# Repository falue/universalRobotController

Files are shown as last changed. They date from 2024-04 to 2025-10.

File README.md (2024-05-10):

# Universal Robot Control (RX/TX)

## Introduction

This repository includes transmitter (TX) and receiver (RX) arduino files for a remote controlled robot of any form.

The transmitter is a custom build to have full control over input mixing, skewing and do all sorts of dependencies.
It depends on a custom PCB, or like a thousand wires.
The receiver end can be a robot or whatever.

This relies on OrangeRx products by hobbyking for Tx/Rx and uses the (legacy) DSM2/DSMX† protocols for a reliable, digital communication.
with a "range of up to 3km (line of sight)".
I'm sure though this works with any RC transmitter that uses iBUs / ppm.

> Based on James Brutons RemoteDSM:
> 
> [https://github.com/XRobots/RemoteDSM ↗](https://github.com/XRobots/RemoteDSM)
> 
> [https://youtu.be/5BfRg9CUMYI ↗](https://youtu.be/5BfRg9CUMYI)

† "*The DSM in DSMX stands for Digital Spectrum Modulation and is what creates pure digital control providing an impenetrable radio link immune to all types of interference.*" ([Soruce ↗](https://www.spektrumrc.com/spm-bs-dsmx.html#:~:text=The%20DSM%20in%20DSMX%20stands,to%20all%20types%20of%20interference.))

# Transmission speed
Depending if you need 10 or 20 channels you can choose to use a second transmitter.
The second transmitter leads to more fluctation and/or longer duration of the main `loop()` though. If you need snappy response times, reconsider using a second transmitter.

|Num of Transmitters|Range (ms)|Average (ms)|Median (ms)|
|--|--|--|--|
|1|30-69|31|32|
|2|28-70|45|33|

# Hardware
## TX
- [Arduino Mega ↗](https://store.arduino.cc/products/arduino-mega-2560-rev3)
- One thousand switches and buttons
- One thousand linear potentiometers
- Two three-axis joysticks (ali express article [1↗](https://de.aliexpress.com/item/4001270851701.html) or [2↗](https://de.aliexpress.com/item/1005002965907648.html)) with a pushbutton
- A custom PCB (files here: [gerber.zip](kicad/universalRobotTx/gerber/gerber.zip) | [kicad](kicad/universalRobotTx))
- A laser cut case (files here: [ai](cad/universal_robot_laser.ai) | [dxf](cad/universal_robot_laser.dxf) | [svg](cad/universal_robot_laser.svg))
- One (or two) [OrangeRX DSMX DSM2 transmitter ↗](https://hobbyking.com/en_us/orangerx-dsmx-dsm2-compatible-2-4ghz-transmitter-module-v1-2.html)
- *..extensive list has to follow*

## RX
- [Arduino Leonardo (or UNO) ↗](https://store.arduino.cc/products/arduino-leonardo-with-headers)
- [Arduino Motor Shield Rev3 ↗](https://store.arduino.cc/products/arduino-motor-shield-rev3)
- One  (or two) [OrangeRx RR12RDTS Receiver ↗](https://hobbyking.com/en_us/orangerx-rr12rdts-receiver-with-s-link-dsm2-dsmx-compatible.html)
- [OrangeRx Program box ↗](https://hobbyking.com/en_us/orangerx-program-box-for-r620x-r1220x-v3-rr12rdts-receivers.html)
- *..extensive list has to follow*

---

# OrangeRx setup

## OrangeRx Receiver re-programming
As the Windows software "[rx_secure_configurator ↗](https://cdn-global-hk.hobbyking.com/media/file/r/x/rx_secure_configurator.zip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)" for the [receiver ↗](https://hobbyking.com/en_us/orangerx-rr12rdts-receiver-with-s-link-dsm2-dsmx-compatible.html) to set some settings on the receiver is **very** buggy, buy the [OrangeRx Program box ↗](https://hobbyking.com/en_us/orangerx-program-box-for-r620x-r1220x-v3-rr12rdts-receivers.html).
1. Connect the jumper to power the receiver from the program box to pin 1 and 2.
2. Set the "out type" from default "*SBus*" to "*iBUS*"
3. Set the *FailSafe" to send "1500" on all channels when losing connection; to be able to detect signal loss on the receiver

## OrangeRx Binding Process
1. Power off remote.
2. Power on robot receiver. Its LED flashes fast yellow to indicate that there is no connection.
2. Press "Bind" button on transmitter.
3. Power on remote (!); keep "Bind" button pressed.
4. remote beeps three times; robot receiver stops flashing and has now a continous light. congrats.
5. From here on out, connection is established.

> 📝 NOTE: Red LED on remote (on the transmitter) does not turn on if no signal is sent to the PPM pin.
> 
> 📝 NOTE: Always power on robot receiver first, then remote.
> 
> 📝 NOTE: If turned off remote while robot receiver is on, restart robot receiver as well to reset connection.
> Turning off robot receiver while remote is still on, restarting robot receiver again auto connects again.

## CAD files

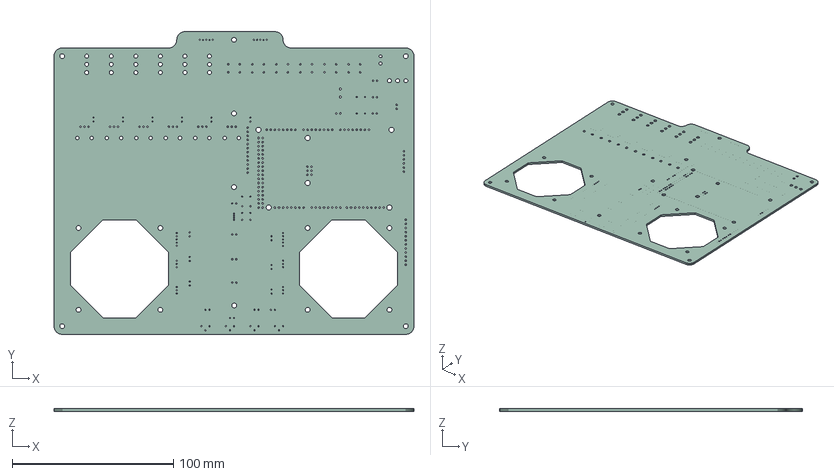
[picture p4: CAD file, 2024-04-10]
kicad/universalRobotTx/universalRobotTx.step
223.5 x 188.0 x 1.60 mm

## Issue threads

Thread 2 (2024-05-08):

Use math functions for changing user input

falue, 2024-05-08:
Use math functions of curves of potis (aka make an exponential potentiometer out of a linear one, or make something irregular)

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

falue, 2024-05-08:
maybe add mini screen for this ?

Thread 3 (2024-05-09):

Servos still jitter

falue, 2024-05-09:
either data from transmitter is sent jittering or the transmission is

solution:
A) solder capacitor into transmitter as planned (might do nothing)
B) additional fast smoothing of the smoothed servo values

did not work
- playing around with capacitor on servo power line

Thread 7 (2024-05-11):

Smoothing of servo PWM - take different loop() speeds into account

falue, 2024-05-11:
TX sends:
`95,100,105,110`
-> one integer per 30ms/loop(), but the RX receives each 2ms/loop():
`95,95,95,95,100,100,100,100,100,100,105,105,105,105,105,110,110,110,110`
-> this will be interpolated as
`98,98,98,100,100,100,100,100,103,105,105,105,105,108,108,108`
(small steep curves, stair like result) instead of a big curve:
`97,98,99,101,102,103,104,105,106,107,108,109110`

Solution:
loop of TX takes around 30ms, loop of RX only around 2ms.
either:
- add ~28ms delay in TX loop (poor choice)
or
- only interpolate values every 15 loops() fo the RX
or
- only interpolate values when the oldValue != currentValue
or
- use time-insensitive smoothing function

falue, 2024-05-11:
or:
```
if(millis() % 30 <= 5) {
  currentSmoothedX = exponentialMovingAverage(X, smoothedValueX, smoothingX);
}
```

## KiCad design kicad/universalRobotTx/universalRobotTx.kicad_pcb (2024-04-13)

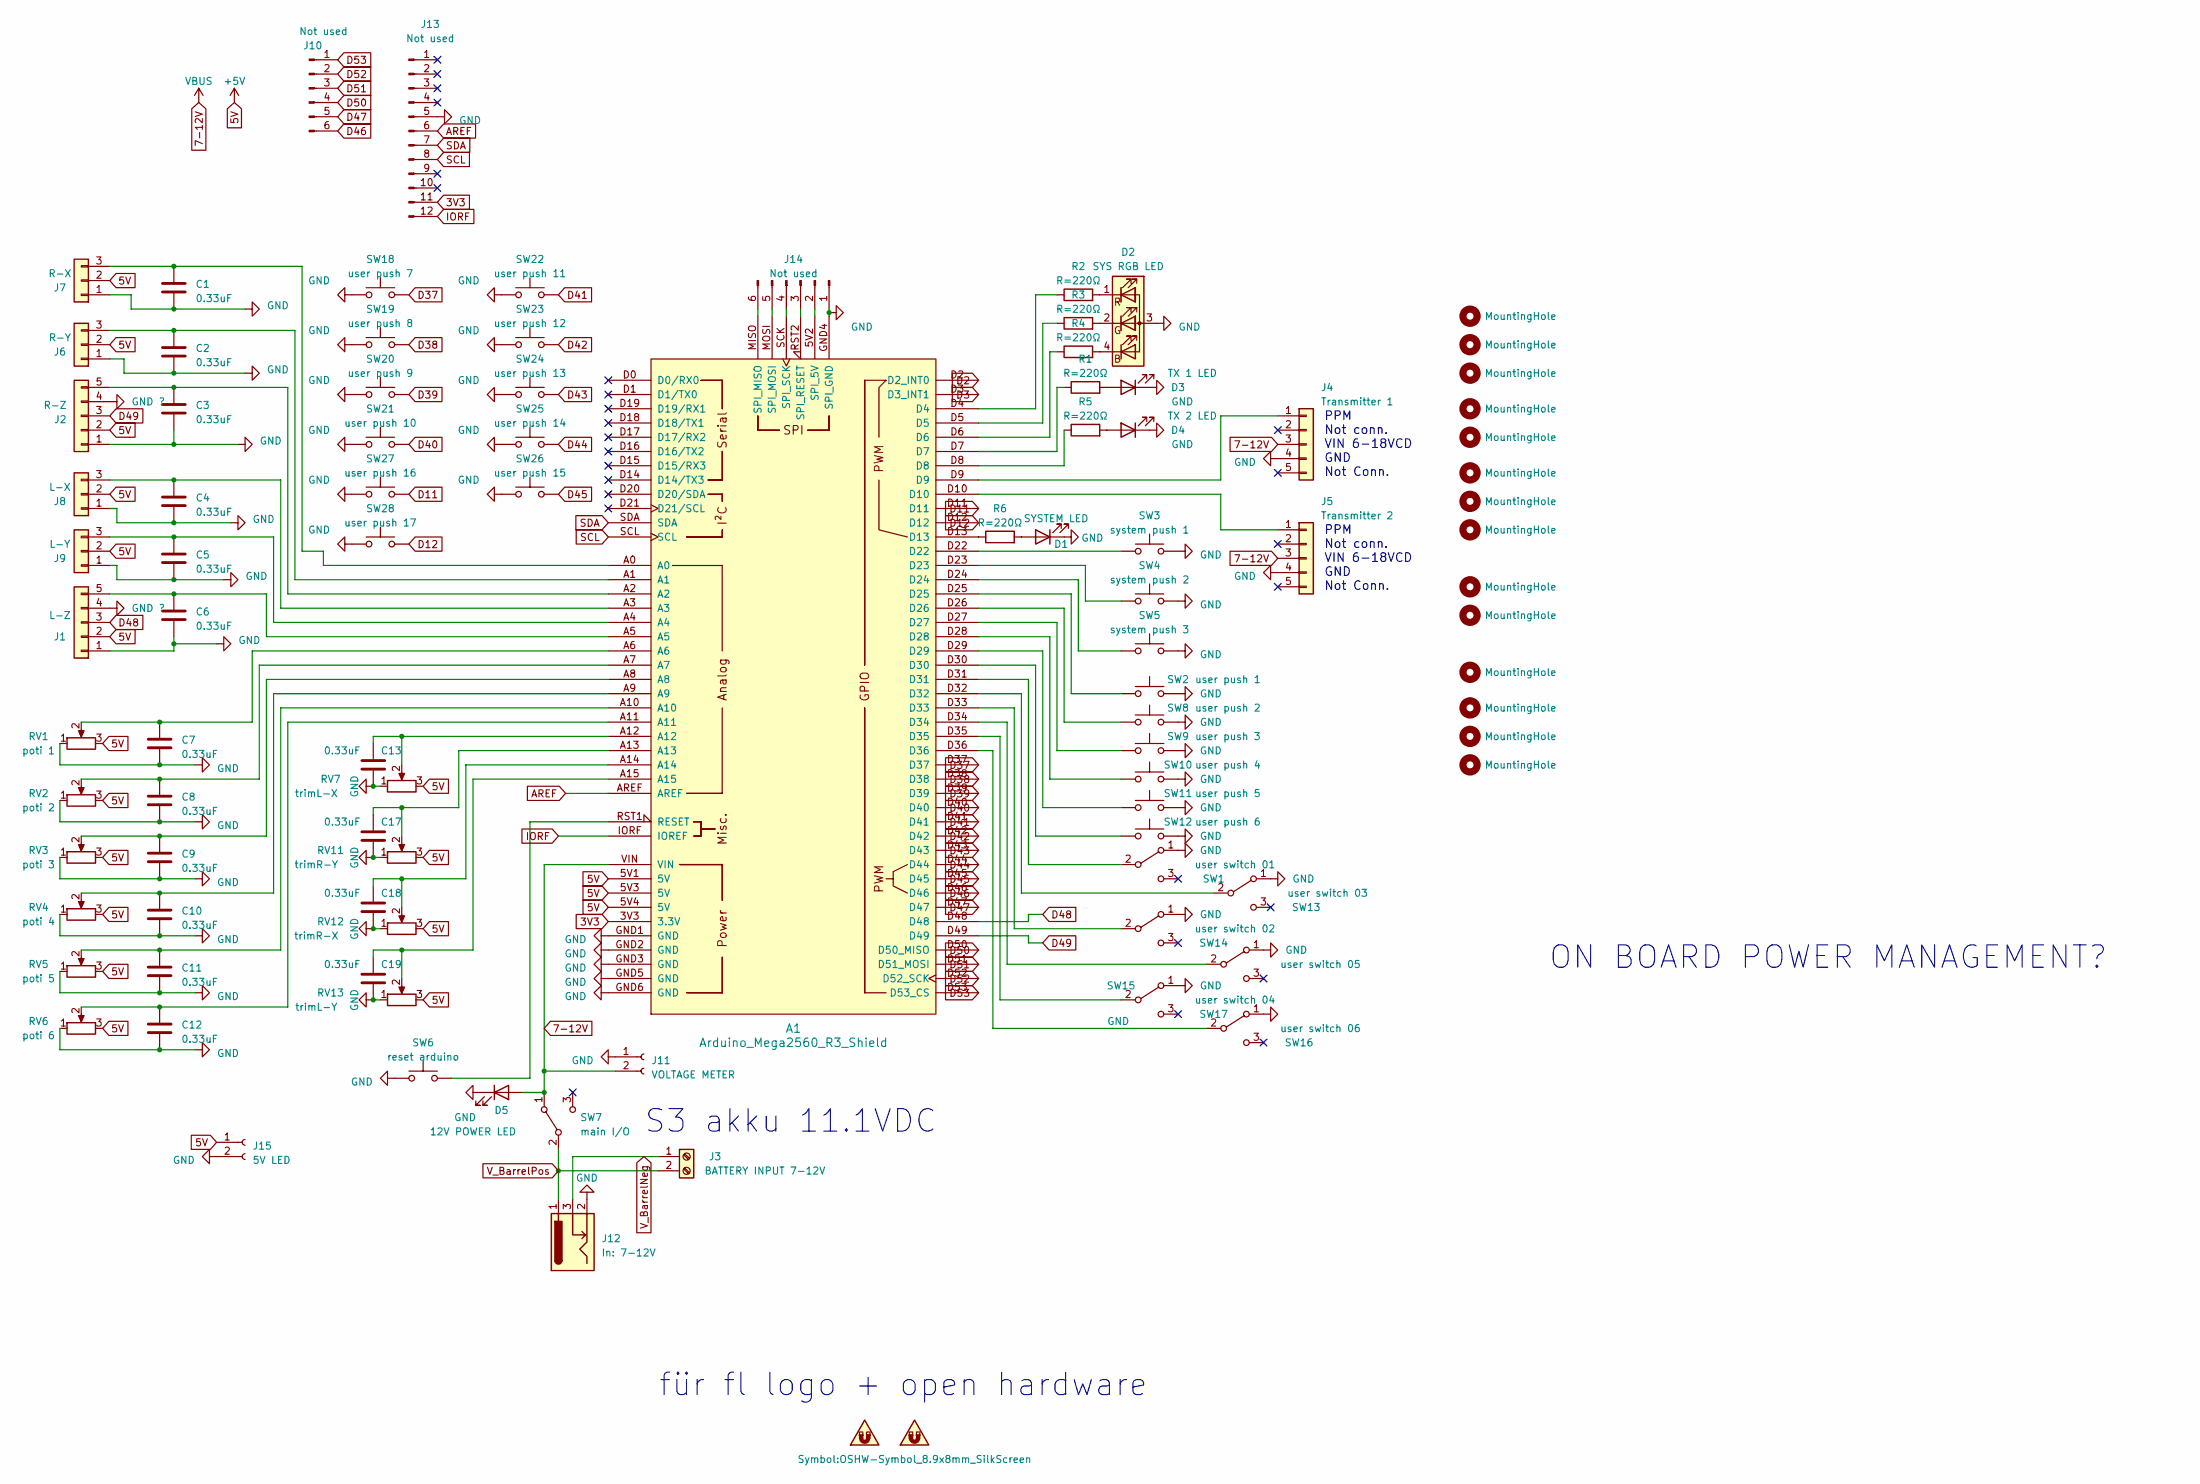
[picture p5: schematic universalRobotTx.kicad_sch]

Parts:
A1: Arduino_Mega2560_R3_Shield
C1, C2, C3, C4, C5, C6, C7, C8, C9, C10, C11, C12, C13, C17, C18, C19: 0.33uF; C_Disc_D7.0mm_W2.5mm_P5.00mm
D1: SYSTEM LED; LED_D3.0mm
D2: SYS RGB LED; LED_D5.0mm-4_RGB_Wide_Pins
D3: TX 1 LED; LED_D3.0mm
D4: TX 2 LED; LED_D3.0mm
D5: 12V POWER LED; LED_D3.0mm
H7: MountingHole; MountingHole_3mm
J1: L-Z; JST_PH_B5B-PH-K_1x05_P2.00mm_Vertical
J2: R-Z; JST_PH_B5B-PH-K_1x05_P2.00mm_Vertical
J3: BATTERY INPUT 7-12V; TerminalBlock_Phoenix_MKDS-1,5-2-5.08_1x02_P5.08mm_Horizont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
J4: Transmitter 1; JST_PH_B5B-PH-K_1x05_P2.00mm_Vertical
J5: Transmitter 2; JST_PH_B5B-PH-K_1x05_P2.00mm_Vertical
J6: R-Y; JST_PH_B3B-PH-K_1x03_P2.00mm_Vertical
J7: R-X; JST_PH_B3B-PH-K_1x03_P2.00mm_Vertical
J8: L-X; JST_PH_B3B-PH-K_1x03_P2.00mm_Vertical
J9: L-Y; JST_PH_B3B-PH-K_1x03_P2.00mm_Vertical
J10, J14: Not used; PinHeader_1x06_P2.54mm_Vertical
J11: VOLTAGE METER; JST_EH_B2B-EH-A_1x02_P2.50mm_Vertical
J12: In: 7-12V; BarrelJack_Kycon_KLDX-0202-xC_Horizontal
J13: Not used; PinHeader_1x12_P2.54mm_Vertical
J15: 5V LED; JST_EH_B2B-EH-A_1x02_P2.50mm_Vertical
R1, R2, R3, R4, R5, R6: R=220Ω; R_Axial_DIN0309_L9.0mm_D3.2mm_P5.08mm_Vertical
RV1: poti 1; Potentiometer_Bourns_PTV09A-1_Single_Vertical
RV2: poti 2; Potentiometer_Bourns_PTV09A-1_Single_Vertical
RV3: poti 3; Potentiometer_Bourns_PTV09A-1_Single_Vertical
RV4: poti 4; Potentiometer_Bourns_PTV09A-1_Single_Vertical
RV5: poti 5; Potentiometer_Bourns_PTV09A-1_Single_Vertical
RV6: poti 6; Potentiometer_Bourns_PTV09A-1_Single_Vertical
RV7: trimL-X; Potentiometer_Bourns_3386X_Horizontal
RV11: trimR-Y; Potentiometer_Bourns_3386X_Horizontal
RV12: trimR-X; Potentiometer_Bourns_3386X_Horizontal
RV13: trimL-Y; Potentiometer_Bourns_3386X_Horizontal
SW1: user switch 01; Toggle_switch_3P_5.08
SW2: user push 1; SW_TH_Tactile_FL_thingy
SW3: system push 1; Drucktaster_FL_Mentor_1852.6231
SW4: system push 2; Drucktaster_FL_Mentor_1852.6231
SW5: system push 3; Drucktaster_FL_Mentor_1852.6231
SW6: reset arduino; Drucktaster_FL_Mentor_1852.6231
SW7: main I/O; Toggle_switch_3P_5.08
SW8: user push 2; SW_TH_Tactile_FL_thingy
SW9: user push 3; SW_TH_Tactile_FL_thingy
SW10: user push 4; SW_TH_Tactile_FL_thingy
SW11: user push 5; SW_TH_Tactile_FL_thingy
SW12: user push 6; SW_TH_Tactile_FL_thingy
SW13: user switch 03; Toggle_switch_3P_5.08
SW14: user switch 02; Toggle_switch_3P_5.08
SW15: user switch 05; Toggle_switch_3P_5.08
SW16: user switch 06; Toggle_switch_3P_5.08
SW17: user switch 04; Toggle_switch_3P_5.08
SW18: user push 7; SW_Push_1P2T_Horizontal_FL_RND_210-00255
SW19: user push 8; SW_Push_1P2T_Horizontal_FL_RND_210-00255
SW20: user push 9; SW_Push_1P2T_Horizontal_FL_RND_210-00255
SW21: user push 10; SW_Push_1P2T_Horizontal_FL_RND_210-00255
SW22: user push 11; SW_Push_1P2T_Horizontal_FL_RND_210-00255
SW23: user push 12; SW_Push_1P2T_Horizontal_FL_RND_210-00255
SW24: user push 13; SW_Push_1P2T_Horizontal_FL_RND_210-00255
SW25: user push 14; SW_Push_1P2T_Horizontal_FL_RND_210-00255
SW26: user push 15; SW_Push_1P2T_Horizontal_FL_RND_210-00255
SW27: user push 16; SW_Push_1P2T_Horizontal_FL_RND_210-00255
SW28: user push 17; SW_Push_1P2T_Horizontal_FL_RND_210-00255

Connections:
3V3: A1.3V3 (3.3V), J13.11
5V: A1.5V1 (5V), A1.5V3 (5V), A1.5V4 (5V), J1.2, J2.2, J6.2, J7.2, J8.2, J9.2, J15.1, RV1.3, RV2.3, RV3.3, RV4.3, RV5.3, RV6.3, RV7.3, RV11.3, RV12.3, RV13.3
7-12V: A1.VIN, D5.2 (A), J4.3, J5.3, J11.2, SW7.1 (A)
AREF: A1.AREF, J13.6
D2: A1.D2 (D2_INT0)
D3: A1.D3 (D3_INT1)
D11: A1.D11, SW27.2
D12: A1.D12, SW28.2
D37: A1.D37, SW18.2
D38: A1.D38, SW19.2
D39: A1.D39, SW20.2
D40: A1.D40, SW21.2
D41: A1.D41, SW22.2
D42: A1.D42, SW23.2
D43: A1.D43, SW24.2
D44: A1.D44, SW25.2
D45: A1.D45, SW26.2
D46: A1.D46, J10.6
D47: A1.D47, J10.5
D48: A1.D48, J1.3
D49: A1.D49, J2.3
D50: A1.D50 (D50_MISO), J10.4
D51: A1.D51 (D51_MOSI), J10.3
D52: A1.D52 (D52_SCK), J10.2
D53: A1.D53 (D53_CS), J10.1
IORF: A1.IORF (IOREF), J13.12
unnamed: A1.A6, C7.1, RV1.2
unnamed: A1.A7, C8.1, RV2.2
unnamed: A1.A8, C9.1, RV3.2
unnamed: A1.A9, C10.1, RV4.2
unnamed: A1.A10, C11.1, RV5.2
unnamed: A1.A11, C12.1, RV6.2
unnamed: A1.A12, C13.1, RV7.2
unnamed: A1.A13, C17.1, RV11.2
unnamed: A1.A14, C18.1, RV12.2
unnamed: A1.A15, C19.1, RV13.2
unnamed: A1.D4, R2.1
unnamed: A1.D5, R3.1
unnamed: A1.D6, R4.1
unnamed: A1.D7, R1.1
unnamed: A1.D8, R5.1
unnamed: A1.D13, R6.1
unnamed: A1.D22, SW3.1
unnamed: A1.D23, SW4.1
unnamed: A1.D24, SW5.1
unnamed: A1.D25, SW2.1
unnamed: A1.D26, SW8.1
unnamed: A1.D27, SW9.1
unnamed: A1.D28, SW10.1
unnamed: A1.D29, SW11.1
unnamed: A1.D30, SW12.1
unnamed: A1.RST1 (RESET), SW6.2
unnamed: A1.5V2 (SPI_5V), J14.2
unnamed: A1.MISO (SPI_MISO), J14.6
unnamed: A1.MOSI (SPI_MOSI), J14.5
unnamed: A1.RST2 (SPI_RESET), J14.3
unnamed: A1.SCK (SPI_SCK), J14.4
unnamed: D1.2 (A), R6.2
unnamed: D2.4 (BK), R4.2
unnamed: D2.2 (GK), R3.2
unnamed: D2.1 (RK), R2.2
unnamed: D3.2 (A), R1.2
unnamed: D4.2 (A), R5.2
unnamed: A1.A5, C6.1, J1.5
unnamed: A1.A2, C3.1, J2.5
unnamed: A1.D9, J4.1
unnamed: A1.D10, J5.1
unnamed: A1.A1, C2.1, J6.3
unnamed: A1.A0, C1.1, J7.3
unnamed: A1.A3, C4.1, J8.3
unnamed: A1.A4, C5.1, J9.3
unnamed: A1.D31, SW1.2 (B)
unnamed: A1.D32, SW13.2 (B)
unnamed: A1.D33, SW14.2 (B)
unnamed: A1.D34, SW15.2 (B)
unnamed: A1.D36, SW16.2 (B)
unnamed: A1.D35, SW17.2 (B)
SCL: A1.SCL, J13.8
SDA: A1.SDA, J13.7
V_BarrelNeg: J3.1, J12.3
V_BarrelPos: J3.2, J12.1, SW7.2 (B)

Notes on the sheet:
PPM Not conn. VIN 6-18VCD GND Not Conn.
ON BOARD POWER MANAGEMENT?
S3 akku 11.1VDC
für fl logo + open hardware

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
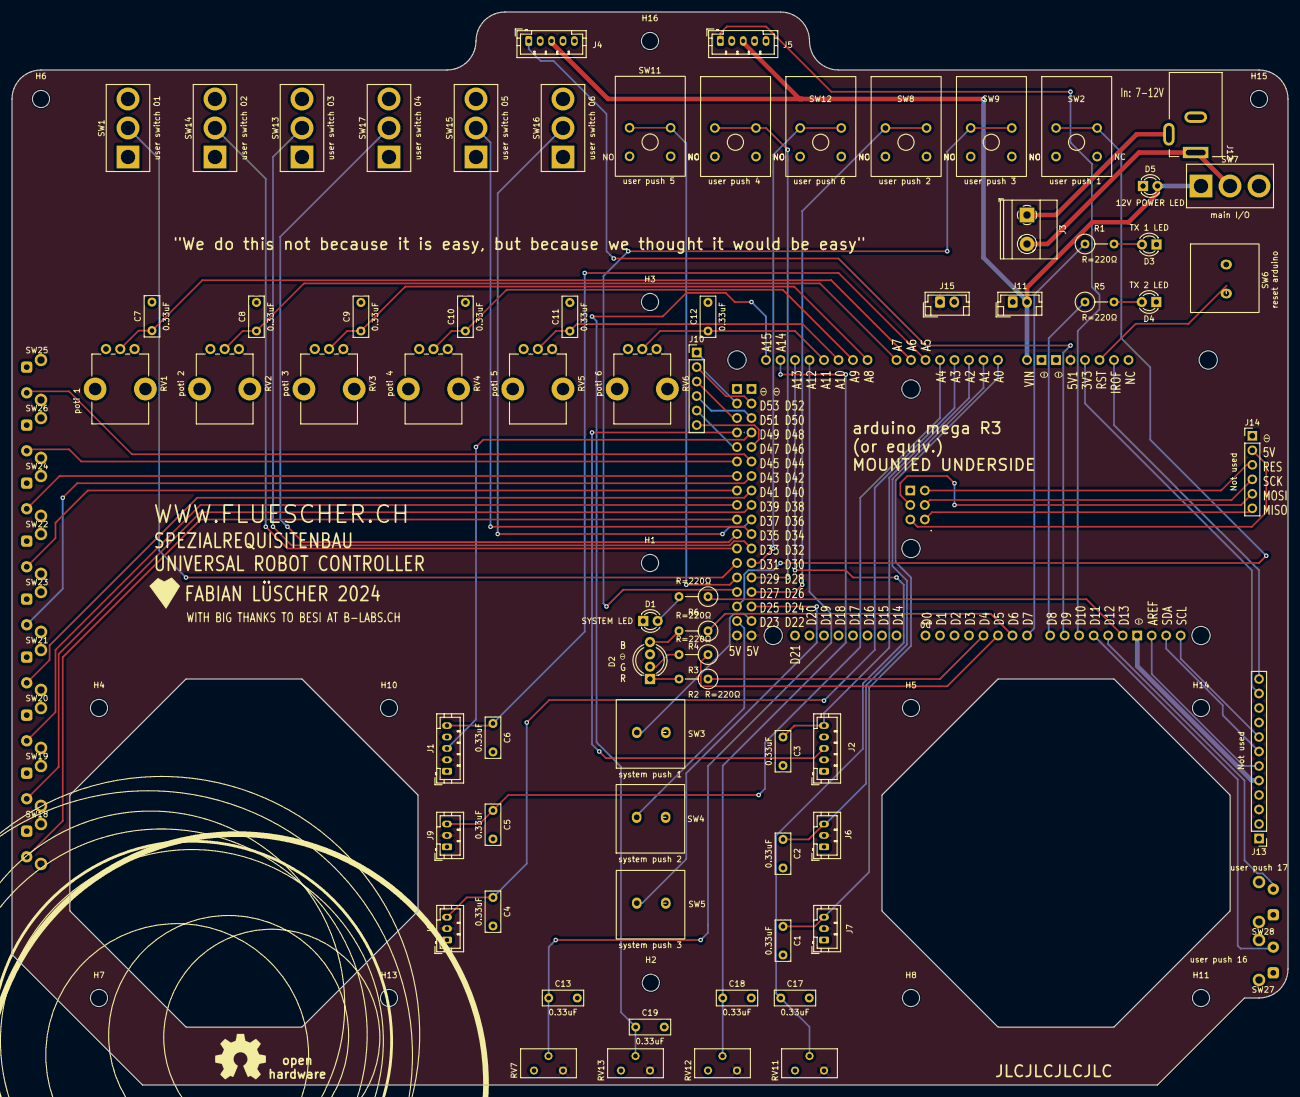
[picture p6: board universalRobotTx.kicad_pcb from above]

Board: 2 copper layers, 223.5 x 188.0 mm, 95 parts (0 on the bottom side), 80 nets.

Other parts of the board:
H1, H2, H3, H4, H5, H6, H8, H10, H11, H13, H14, H15, H16: MountingHole; MountingHole_3mm

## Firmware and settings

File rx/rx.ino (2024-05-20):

#include <IBusBM.h>  // https://github.com/bmellink/IBusBM
#include <Servo.h>

IBusBM IBus; // IBus object

Servo servoX;
Servo servoY;

// Options
bool enableDrive = false;          // Set by switch 2
bool enableHeadMovements = false;  // Set by switch 1
bool fakeRemoteInputs = false;     // If you do not have a RX connected, try this. Generates ramp-ups and -downs of joystiuck movement.
bool forceDisableMotors = false;    // Disable effective motor control, but keep calculations & serial prints

// Servos
int servoXPin = 2;
int servoYPin = 10;

// DC Motors
int directionPinA = 13;
int pwmPinA = 11;
int brakePinA =  8;

int directionPinB = 12;
int pwmPinB = 3;
int brakePinB =9;

// Remote channels
int joystickLX = 1500;
int joystickLY = 1500;
int joystickLZ = 1500;
int jostickRX = 1500;
int jostickRY = 1500;
int jostickRZ = 1500;
bool joyBtnL = false;
bool joyBtnR = false;
bool enableAcceleratedSmoothing = false;

// Unused btns
bool disableSteering = false;
bool userBtn1 = false;
bool userBtn2 = false;
// bool userBtn3 = false;  // not used
// bool userBtn4 = false;  // not used
// bool userBtn5 = false;  // not used
// bool userBtn6 = false;  // not used
int poti1 = 1500;
int poti2 = 1500;

bool decodedButtons0[4];
bool decodedButtons1[4];

// Smoothing servos
float smoothedValueX = float(jostickRX);
float smoothedValueY = float(jostickRY);
float smoothedValueZ = float(jostickRZ);

float currentSmoothedX = smoothedValueX;
float currentSmoothedY = smoothedValueY;

// Limit the max speed of the robot
// 0-254 *or* 0-100. This is up for dabate. The latter is mentioned in the docs of the
// motor shield r3 but a weird thing, usually things like that are 0-254.
int maxSpeed = 100;  // Changed by poti1
int minSpeed = 33;   // Below this, the motors do not turn bc. of friction and not being spherical cows in space
float headMovementSmoothing = 0.01;

// fakeRemoteInputs
int directionX = 1, directionY = 1, directionZ = 1;
int phase = 0;
int step = 2;
const int startValue = 1000;
const int endValue = 2000;

void setup() {
  delay(1666);

  Serial.begin(115200);
  
  // Establish IBus connection to receiver
  //   Change to Serial1 = D0 (or Serial2 or 3 for on ard mega or so) port when required
  //   The servo library conflicts with the interrupts used by the IBus library -
  //   Therefore, use second argument "IBUSBM_NOTIMER" to call the IBus.loop() function manually in the main loop
  IBus.begin(Serial1, IBUSBM_NOTIMER);

  // Attach head servos
  servoX.attach(servoXPin);
  servoY.attach(servoYPin);

  // Define motor pins
  pinMode(directionPinA, OUTPUT);
  pinMode(pwmPinA, OUTPUT);
  pinMode(brakePinA, OUTPUT);

  pinMode(directionPinB, OUTPUT);
  pinMode(pwmPinB, OUTPUT);
  pinMode(brakePinB, OUTPUT);
}

void loop() {
  if(!fakeRemoteInputs) {
    readChannels();
  } else {
    fakeJoystickValues();
  }

  detectLossOfSignal();

  debugPrints();

  drive(joystickLX, joystickLY, joystickLZ);

  if(enableDrive) {
    if(joyBtnL) {
      quickturn("joyBtnL", -180);
    }
    if(joyBtnR) {
      quickturn("joyBtnR", 180);
    }
    if(userBtn1) {
      quickturn("userBtn1", -5);
    }
    if(userBtn2) {
      quickturn("userBtn2", 5);
    }
  }
  

  if(enableHeadMovements) {
    if(!servoX.attached()) {
      servoX.attach(servoXPin);
      servoY.attach(servoYPin);
    }
    headMovement(jostickRX, jostickRY, jostickRZ);
  } else if(servoX.attached()) {
    servoX.detach();
    servoY.detach();
  }

  Serial.println("");
  // delay(5);  // Do not delay because IBus.loop() must be called as fast as possible
}


void fakeJoystickValues() {
    if(phase == 0 || phase == 3 || phase >= 4) {
      // Update Y
      if (joystickLY >= endValue || joystickLY <= startValue) {
          directionY *= -1;  // Reverse the direction
      }
      joystickLY += directionY * step;
      
      if(joystickLY <= startValue) {
        joystickLY = 1500;
        directionY = 1;
        phase++;
        delay(2000);
      }
    }

    if(phase == 1 || phase == 3 || phase >= 4) {
      // Update X
      if (joystickLX >= endValue || joystickLX <= startValue) {
          directionX *= -1;  // Reverse the direction
      }
      joystickLX += directionX * step;

      if(joystickLX <= startValue) {
        joystickLX = 1500;
        directionX = 1;
        phase++;
        delay(2000);
      }
    }

    if(phase == 2 || phase >= 4) {
      // Update Z
      if (joystickLZ >= endValue || joystickLZ <= startValue) {
          directionZ *= -1;  // Reverse the direction
      }
      joystickLZ += directionZ * step;
      
      if(joystickLZ <= startValue) {
        joystickLZ = 1500;
        directionZ = 1;
        phase++;
        delay(2000);
      }
    }

    String dirArrow = "";

    if(joystickLY > 1500) dirArrow += "▲";
    if(joystickLY < 1500) dirArrow += "▼";

    if(joystickLX > 1500) dirArrow += "►";
    if(joystickLX < 1500) dirArrow += "◄";

    if(joystickLZ > 1500) dirArrow += "⤵";
    if(joystickLZ < 1500) dirArrow += "⤴";

    // Output the current values and mixes to the Serial Monitor
    Serial.print("LX: "); Serial.print(joystickLX);
    Serial.print("\tLY: "); Serial.print(joystickLY);
    Serial.print("\tLZ: "); Serial.print(joystickLZ);
    Serial.print("\tsteering: ");
    Serial.print(dirArrow);
}

void readChannels() {
  // Call internal loop function to update the communication to the receiver.
  //   Needed if IBus.begin(); is called with second parameter "IBUSBM_NOTIMER"
  IBus.loop();
  int correction = -19;  // Somehow all the values are shifted 11-26 points (weighted median ~19)

  /*
  Sent by TX1:
    ch0: joystickLX
    ch1: joystickLY
    ch2: joystickLZ
    ch3: joystickRX
    ch4: joystickRY
    ch5: joystickRZ
    ch6: encodedButtons0 = {0: toggleSwitch1 1: toggleSwitch2 2: toggleSwitch3 3: toggleSwitch4}
    ch7: encodedButtons1 = {0: joyBtnL       1: joyBtnR       2: userBtn1      3: userBtn2}
    ch8: poti1
    ch9: poti2
  
  Sent by TX2 (if enabled):
    ch10: poti3
    ch11: poti4
    ch12: poti5
    ch13: poti6
    ch14: encodedButtons2 = {0: toggleSwitch5 1: toggleSwitch6 2: userBtn3  3: userBtn4}
    ch15: encodedButtons3 = {0: userBtn5      1: userBtn6      2: userBtn7  3: userBtn8}
    ch16: encodedButtons4 = {0: userBtn9      1: userBtn10     2: userBtn11 3: userBtn12}
    ch17: encodedButtons5 = {0: userBtn13     1: userBtn14     2: userBtn15 3: userBtn18}
    ch18: encodedButtons6 = {0: userBtn19     1: sysBtn1       2: sysBtn2   3: sysBtn3}
    ch19: 1500 (NC - not connected)
  */

  // Get the latest IBus data from cached data
  //   IMPORTANT: Somehow, some (?) channels are reordered by the TX or (!) RX
  joystickLY = IBus.readChannel(0) + correction;
  joystickLZ = IBus.readChannel(1) + correction;
  joystickLX = IBus.readChannel(2) + correction;
  jostickRX = IBus.readChannel(3) + correction;
  jostickRY = IBus.readChannel(4) + correction;
  jostickRZ = IBus.readChannel(5) + correction;
  
  // Add bool array to function because memory leaks
  decodeButtons(IBus.readChannel(6) + correction, decodedButtons0);
  decodeButtons(IBus.readChannel(7) + correction, decodedButtons1);

  enableDrive = decodedButtons0[0];
  enableHeadMovements = decodedButtons0[1];
  enableAcceleratedSmoothing = decodedButtons0[2];
  disableSteering = decodedButtons0[3];

  joyBtnL = decodedButtons1[0];
  joyBtnR = decodedButtons1[1];
  userBtn1 = decodedButtons1[2];
  userBtn2 = decodedButtons1[3];

  poti1 = IBus.readChannel(8) + correction;
  maxSpeed = map(poti1, 1000,2000, minSpeed,254);

  poti2 = IBus.readChannel(9) + correction;
  headMovementSmoothing = map(poti2, 1000,2000, 1,5000) / 100000.0;  // 0.01 is good, but can be less or up to 1
}

void debugPrints() {
  Serial.print("\tLX: ");
  Serial.print(joystickLX);
  Serial.print("\tLY: ");
  Serial.print(joystickLY);
  Serial.print("\tLZ: ");
  Serial.print(joystickLZ);
  Serial.print("\tRX: ");
  Serial.print(jostickRX);
  Serial.print("\tRY: ");
  Serial.print(jostickRY);
  Serial.print("\tRZ: ");
  Serial.print(jostickRZ);
  Serial.print("\tJBtnL: ");
  Serial.print(joyBtnL);
  Serial.print("\tJBtnR: ");
  Serial.print(joyBtnR);
  Serial.print("\tenDrive: ");
  Serial.print(enableDrive);
  Serial.print("\tenHead: ");
  Serial.print(enableHeadMovements);
  Serial.print("\tswitch3: ");
  Serial.print(enableAcceleratedSmoothing);
  Serial.print("\tswitch4: ");
  Serial.print(disableSteering);
  Serial.print("\tBtn1: ");
  Serial.print(userBtn1);
  Serial.print("\tBtn2: ");
  Serial.print(userBtn2);
  Serial.print("\tpot1: ");
  Serial.print(poti1);
  Serial.print("\tpot2: ");
  Serial.print(poti2);

  Serial.print("\tmaxSpeed: ");
  Serial.print(maxSpeed);
  Serial.print("\theadSmooth: ");
  Serial.print(headMovementSmoothing);
}

int calculateMotorSpeed(int Y, int X, int Z, char motorSide) {
  // TODO: Z is ignored now
  float mixer = 1.0;
  float minMixer = 0.5;
  // if full forward/backward and left, use 0.5
  // if full left, use 1.0
  mixer = 2.0 - map((abs(Y)+abs(X))*100, 0,maxSpeed*100, minMixer*100,100) / 100.0;
  mixer = clamp(mixer, 0.1, 1.0);
  
  int leftMotor = Y + int(X*mixer);
  int rightMotor = Y - int(X*mixer);
  
  leftMotor = clamp(leftMotor, -maxSpeed, maxSpeed);
  rightMotor = clamp(rightMotor, -maxSpeed, maxSpeed);
  
  if (motorSide == 'L') {
    Serial.print("\tmixer: ");
    Serial.print(mixer);
    return leftMotor;
  } else {
    return rightMotor;
  }
}

void drive(int X, int Y, int Z) {
  /* Terack movement */
  int deathZone = 30;  // 35, 50 works too
  // If walues chang only very little, nothing is being controlled, i.e. robot should be idling
  bool idle = isInDeathZone(X, 1500, deathZone) && isInDeathZone(Y, 1500, deathZone) && isInDeathZone(Z-165, 1500, deathZone);  // Z-165 because cheap joystick & cannot be trimmed

  // Values between 1000 and 2000
  X = clampMap(X, 1000,2000, -maxSpeed,maxSpeed);
  Y = clampMap(Y, 1000,2000, -maxSpeed,maxSpeed);
  Z = clampMap(Z, 1000,2000, maxSpeed,-maxSpeed);  // invert Z axis for some reason

  if(disableSteering) {
    X = 0;
  }

  // TODO: use Z for something
  /*if(abs(Z-1500) > abs(X-1500)) {
    X = Z < 1500 ? min(X, Z) : max(X, Z);
  }*/

  if(idle || !enableDrive) {
    // Remote is not touched - engange breaks and do nothing
    digitalWrite(brakePinA, HIGH);
    digitalWrite(brakePinB, HIGH);
    analogWrite(pwmPinA, 0);
    analogWrite(pwmPinB, 0);
  } else {
    // Release breaks
    digitalWrite(brakePinA, LOW);
    digitalWrite(brakePinB, LOW);

    // Mix X Y Z together
    // Get values between -maxSpeed and maxSpeed
    int motorL = calculateMotorSpeed(Y, X, Z, 'L');
    int motorR = calculateMotorSpeed(Y, X, Z, 'R');

    // Set direction
    digitalWrite(directionPinA, motorL < 0);  // LOW to reverse
    digitalWrite(directionPinB, motorR < 0);  // LOW to reverse

    Serial.print("\tmotorL: ");
    Serial.print(motorL);
    Serial.print("\tdir_motorL: ");
    Serial.print(motorL < 0 ? "back" : "forward");
    Serial.print("\tmotorR: ");
    Serial.print(motorR);
    Serial.print("\tdir_motorR: ");
    Serial.print(motorR < 0 ? "back" : "forward");

    // Power to the motors
    if(!forceDisableMotors) {
      analogWrite(pwmPinA, abs(motorL));  // abs makes out of -50 +50
      analogWrite(pwmPinB, abs(motorR));  // abs makes out of -50 +50
    }
  }

  Serial.print("\tmotorL: ");
  Serial.print(0);
  Serial.print("\tdir_motorL: ");
  Serial.print("idle");
  Serial.print("\tmotorR: ");
  Serial.print(0);
  Serial.print("\tdir_motorR: ");
  Serial.print("idle");
}


 bool debounce(String btnName) {
  bool btnState = true;
  while(btnState) {
    readChannels();
    if (btnName == "joyBtnL") {
      btnState = joyBtnL;
    } else if (btnName == "joyBtnR") {
      btnState = joyBtnR;
    } else if (btnName == "userBtn1") {
      btnState = userBtn1;
    } else if (btnName == "userBtn2") {
      btnState = userBtn2;
    } else {
      Serial.println("This btn has to be hard coded here to be debounced");
      btnState = false;
    }
    Serial.print(btnName);
    Serial.println(" - wait for btn release");
    delay(1);
  }
}

void quickturn(String btnName, int deg) {
  // On the press of a joystick or user button, make a quickturn left or right
  debounce(btnName);  // Waits for btn release

  // Release breaks
  digitalWrite(brakePinA, LOW);
  digitalWrite(brakePinB, LOW);
  digitalWrite(directionPinA, deg > 0 ? LOW : HIGH);   // LOW to reverse
  digitalWrite(directionPinB, deg < 0 ? LOW : HIGH);   // LOW to reverse
  analogWrite(pwmPinA, 100);
  analogWrite(pwmPinB, 100);
  int durationOfTurn = abs(deg)*2.6;
  Serial.println("Fast turn duration: ");
  Serial.print(durationOfTurn);
  delay(durationOfTurn); // Depends on ground and grip of tracks
}

bool isInDeathZone(int value, int idleValue, int deathZone) {
  bool isBelow = value < idleValue - deathZone;
  bool isAbove = value > idleValue + deathZone;
  return !(isBelow || isAbove);
}

// Function to calculate exponential moving average for a given sensor value
float exponentialMovingAverage(float newValue, float& smoothedValue, float smoothingFactor) {
  // smoothingFactor: 1=no smoothing; 0.0001 = much please yes smoothing but slow
  smoothedValue = (newValue * smoothingFactor) + (smoothedValue * (1 - smoothingFactor));
  return smoothedValue;
}

void headMovement(int X, int Y, int Z) {
  /* Servo Head movement */
  // Values between 1000 and 2000
  // No matter if the stick is leaning halfway in any direction, but its turned
  //   fully, always take the bigger (or smaller) value of Z
  if(abs(Z-1500) > abs(X-1500)) {
    X = Z < 1500 ? min(X, Z) : max(X, Z);
  }

  // Smooth out the signal
  float smoothingX = headMovementSmoothing;  // Depends on loop speed
  float smoothingY = smoothingX/2.0;  // Depends on loop speed

  // If X much greater than smoothedValueX, decrease smoothingX
  //   eg. if moving stick fast, increase responsiveness
  if(enableAcceleratedSmoothing) {
    if(abs(X - smoothedValueX) > 100) {
      smoothingX *= abs(X - smoothedValueX)/10;
    } else if(abs(Y - smoothedValueY) > 100) {
      smoothingY *= abs(Y - smoothedValueY)/10;
    }
    smoothingX = clamp(smoothingX, 0.0, .1);
    smoothingY = clamp(smoothingY, 0.0, .1);
  }

  currentSmoothedX = exponentialMovingAverage(X, smoothedValueX, smoothingX);
  currentSmoothedY = exponentialMovingAverage(Y, smoothedValueY, smoothingY);
  // float currentSmoothedZ = exponentialMovingAverage(Z, smoothedValueZ, 0.1);

  int servoValueX = map(currentSmoothedX, 1000, 2000, 1750, 2300);  // left, right
  servoX.writeMicroseconds(servoValueX);
  // Recenter head vertically
  int servoValueY = map(currentSmoothedY, 1000, 2000, 2050, 1675);  // up, down
  //servoValueY = clamp(servoValueY, 1675, 2050);  // recenter?
  servoY.writeMicroseconds(servoValueY);
}

int clamp(int value, int min, int max) {
   return value > max ? max : value < min ? min : value;
}

float clamp(float value, float min, float max) {
   return value > max ? max : value < min ? min : value;
}

int clampMap(int value, int valueFrom, int valueTo, int from, int to) {
  if(value < valueFrom) value = valueFrom;
  if(value > valueTo) value = valueTo;
  return map(value, valueFrom, valueTo, from, to);
}

void detectLossOfSignal() {
  // TODO: Does not work
  int failsaveValues = joystickLX + joystickLY + joystickLZ + jostickRX + jostickRY + jostickRZ + joyBtnL + joyBtnR + enableDrive + enableHeadMovements;
  int defaultValueSum = 8623;  //  technically: 6*1500 + 4*0, but IRL: 5*1500+1123 (first channel is 1123?!)
  if(failsaveValues == defaultValueSum) {  // Todo: Loss of signal detection somehow. Kind of the same as the idle state?!
    while(failsaveValues == defaultValueSum) {
      Serial.println("Loss of signal - wait for reconnection");
      readChannels();
      failsaveValues = joystickLX + joystickLY + joystickLZ + jostickRX + jostickRY + jostickRZ + joyBtnL + joyBtnR + enableDrive + enableHeadMovements;
      delay(25);
    }
  }
}

// Decode int from 1000 to 2000 and get array of 4 boolean values
bool* decodeButtons(int encodedValue, bool* buttonStates) {
    // Jitter of +/-32 can be handled
    // static bool buttonStates[4];  // Static to preserve state after the function returns

    // Define the exact encoded values for each combination of button states
    int encodedStates[16] = {
        1000, // 0000
        1066, // 0001
        1133, // 0010
        1200, // 0011
        1266, // 0100
        1333, // 0101
        1400, // 0110
        1466, // 0111
        1533, // 1000
        1600, // 1001
        1666, // 1010
        1733, // 1011
        1800, // 1100
        1866, // 1101
        1933, // 1110
        2000  // 1111
    };

    // Find the closest encoded state
    int closestIndex = 0;
    int smallestDifference = abs(encodedValue - encodedStates[0]);
    for (int i = 1; i < 16; i++) {
        int diff = abs(encodedValue - encodedStates[i]);
        if (diff < smallestDifference) {
            smallestDifference = diff;
            closestIndex = i;
        }
    }

    // Decode the closest index into button states
    buttonStates[0] = (closestIndex & 1) != 0;    // Least significant bit
    buttonStates[1] = (closestIndex & 2) != 0;    // Second bit
    buttonStates[2] = (closestIndex & 4) != 0;    // Third bit
    buttonStates[3] = (closestIndex & 8) != 0;    // Most significant bit

    return buttonStates;
}

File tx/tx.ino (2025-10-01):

/* 
  UNIVERSAL ROBOT CONTROLLER by FL
  with custom PCB
  based on james brutons remote controller
*/

// OPTIONS
bool trim = true;     // If true, poti 7,8,9,10 trim LX,LY,RX,RY. If false, those potis are not used.
int trimRange = 512;  // Plus minus half of that trims LX,LY,RX,RY
bool useSecondTransmitter = false;  // Send all btns and switches data over the second transmitter
String steeringLayout = "maxControl";
    // "conventional" => Use both joysticks with all three axis and their buttons, some switches, btns and potis (used for ProSenectute Robi), if useSecondTransmitter = true, use all buttons
    // "maxControl" => Use one joystick with one joyBtn, max use of buttons, switches and potis on one Transmitter module


// USER INPUT -------------------------------------
int toggleSwitch1Pin = 31;  // Switch on top, left
int toggleSwitch2Pin = 33;  // Switch on top
int toggleSwitch3Pin = 32;  // Switch on top
int toggleSwitch4Pin = 35;  // Switch on top
int toggleSwitch5Pin = 34;  // Switch on top
int toggleSwitch6Pin = 36;  // Switch on top, right

int userBtn1Pin = 29;  // push button on top, left
int userBtn2Pin = 28;  // push button on top
int userBtn3Pin = 30;  // push button on top
int userBtn4Pin = 26;  // push button on top
int userBtn5Pin = 27;  // push button on top
int userBtn6Pin = 25;  // push button on top, right

int userBtn7Pin = 44;   // push button on side left, top
int userBtn8Pin = 45;   // push button on side left
int userBtn9Pin = 43;   // push button on side left
int userBtn10Pin = 41;  // push button on side left
int userBtn11Pin = 42;  // push button on side left
int userBtn12Pin = 40;  // push button on side left
int userBtn13Pin = 39;  // push button on side left
int userBtn14Pin = 38;  // push button on side left
int userBtn15Pin = 37;  // push button on side left, bottom

int userBtn18Pin = 12;  // PWM, push button on side right, top
int userBtn19Pin = 11;  // PWM, push button on side right, bottom

int joystickLXPin = A4;  // A3
int joystickLYPin = A3;  // A4
int joystickLZPin = A5;  // A5
int joyBtnLPin = 48;  // push button on top L joystick

int joystickRXPin = A1;  // A0
int joystickRYPin = A0;  // A1
int joystickRZPin = A2;  // A2
int joyBtnRPin = 49; // push button on top R joystick

int poti1Pin = A6;   // Poti on top, left
int poti2Pin = A7;   // Poti on top
int poti3Pin = A8;   // Poti on top
int poti4Pin = A9;   // Poti on top
int poti5Pin = A10;  // Poti on top
int poti6Pin = A11;  // Poti on top, right

int poti7Pin = A12;  // Poti bottom, left - maybe shifts joystickLX value directly?
int poti8Pin = A15;  // Poti bottom - maybe shifts joystickLY value directly?
int poti9Pin = A14;  // Poti bottom - maybe shifts joystickRX value directly?
int poti10Pin = A13; // Poti bottom, right - maybe shifts joystickRY value directly?

// SYSTEM -----------------------------------------
int sysBtn1Pin = 22;  // System button center, top
int sysBtn2Pin = 23;  // System button center
int sysBtn3Pin = 24;  // System button center, bottom

int transmitter1PpmPin = 9;   // PWM
int transmitter2PpmPin = 10;  // PWM

int systemLEDPin = 13;  // PWM, Same as built in
int tx1LEDPin = 7;      // PWM
int tx2LEDPin = 8;      // PWM
int systemLEDrPin = 6;  // PWM
int systemLEDgPin = 4;  // PWM
int systemLEDbPin = 5;  // PWM


// INITIAL VALUES
bool toggleSwitch1 = false;
bool toggleSwitch2 = false;
bool toggleSwitch3 = false;
bool toggleSwitch4 = false;
bool toggleSwitch5 = false;
bool toggleSwitch6 = false;
bool userBtn1 = false;
bool userBtn2 = false;
bool userBtn3 = false;
bool userBtn4 = false;
bool userBtn5 = false;
bool userBtn6 = false;
bool userBtn7 = false;
bool userBtn8 = false;
bool userBtn9 = false;
bool userBtn10 = false;
bool userBtn11 = false;
bool userBtn12 = false;
bool userBtn13 = false;
bool userBtn14 = false;
bool userBtn15 = false;
bool userBtn18 = false;
bool userBtn19 = false;
int joystickLX = 0;
int joystickLY = 0;
int joystickLZ = 0;
bool joyBtnL = false;
int joystickRX = 0;
int joystickRY = 0;
int joystickRZ = 0;
bool joyBtnR = false;
int poti1 = 0;
int poti2 = 0;
int poti3 = 0;
int poti4 = 0;
int poti5 = 0;
int poti6 = 0;
int poti7 = 0;
int poti8 = 0;
int poti9 = 0;
int poti10 = 0;
bool sysBtn1 = false;
bool sysBtn2 = false;
bool sysBtn3 = false;

// VAR VARS
bool DEBUG = true;  // Prints to console, makes stuff slow, kinda
int ledBrightness = 6;

void setup() {
  delay(1000);
  Serial.println("==============================");
  Serial.begin(115200);
  Serial.println("");
  Serial.println("Setup");
  Serial.println("==============================");
  
  pinMode(toggleSwitch1Pin, INPUT_PULLUP);
  pinMode(toggleSwitch2Pin, INPUT_PULLUP);
  pinMode(toggleSwitch3Pin, INPUT_PULLUP);
  pinMode(toggleSwitch4Pin, INPUT_PULLUP);
  pinMode(toggleSwitch5Pin, INPUT_PULLUP);
  pinMode(toggleSwitch6Pin, INPUT_PULLUP);
  pinMode(userBtn1Pin, INPUT_PULLUP);
  pinMode(userBtn2Pin, INPUT_PULLUP);
  pinMode(userBtn3Pin, INPUT_PULLUP);
  pinMode(userBtn4Pin, INPUT_PULLUP);
  pinMode(userBtn5Pin, INPUT_PULLUP);
  pinMode(userBtn6Pin, INPUT_PULLUP);
  pinMode(userBtn7Pin, INPUT_PULLUP);
  pinMode(userBtn8Pin, INPUT_PULLUP);
  pinMode(userBtn9Pin, INPUT_PULLUP);
  pinMode(userBtn10Pin, INPUT_PULLUP);
  pinMode(userBtn11Pin, INPUT_PULLUP);
  pinMode(userBtn12Pin, INPUT_PULLUP);
  pinMode(userBtn13Pin, INPUT_PULLUP);
  pinMode(userBtn14Pin, INPUT_PULLUP);
  pinMode(userBtn15Pin, INPUT_PULLUP);
  pinMode(userBtn18Pin, INPUT_PULLUP);
  pinMode(userBtn19Pin, INPUT_PULLUP);
  pinMode(joystickLXPin, INPUT);
  pinMode(joystickLYPin, INPUT);
  pinMode(joystickLZPin, INPUT);
  pinMode(joyBtnLPin, INPUT_PULLUP);
  pinMode(joystickRXPin, INPUT);
  pinMode(joystickRYPin, INPUT);
  pinMode(joystickRZPin, INPUT);
  pinMode(joyBtnRPin, INPUT_PULLUP);
  pinMode(poti1Pin, INPUT);
  pinMode(poti2Pin, INPUT);
  pinMode(poti3Pin, INPUT);
  pinMode(poti4Pin, INPUT);
  pinMode(poti5Pin, INPUT);
  pinMode(poti6Pin, INPUT);
  pinMode(poti7Pin, INPUT);
  pinMode(poti8Pin, INPUT);
  pinMode(poti9Pin, INPUT);
  pinMode(poti10Pin, INPUT);
  pinMode(sysBtn1Pin, INPUT_PULLUP);
  pinMode(sysBtn2Pin, INPUT_PULLUP);
  pinMode(sysBtn3Pin, INPUT_PULLUP);

  pinMode(transmitter1PpmPin, OUTPUT);
  pinMode(transmitter2PpmPin, OUTPUT);
  pinMode(systemLEDPin, OUTPUT);   // Maybe not; same as built in?
  pinMode(tx1LEDPin, OUTPUT);
  pinMode(tx2LEDPin, OUTPUT);
  pinMode(systemLEDrPin, OUTPUT);
  pinMode(systemLEDgPin, OUTPUT);
  pinMode(systemLEDbPin, OUTPUT);
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

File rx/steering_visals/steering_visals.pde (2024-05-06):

import processing.serial.*;

Serial myPort;  // Create object from Serial class
String val;     // Data received from the serial port
int LX = 1500, LY = 1500, LZ = 1500;
int motorL = 0, motorR = 0;
String dir_motorL = "forward", dir_motorR = "forward";

Boolean use_Serial = true;

float handleX, handleY; // Position of the joystick handle
float handleRadius = 50; // Radius of the draggable handle
boolean dragging = false; // Is the handle being dragged?

int heightWindow = 666;
int diameter = 100;
int radius = diameter / 2;
int circleX = radius + 20;
int circleY = heightWindow - radius - 20;

void setup() {
  size(1000, 666); // Set the window size to 1000x666 pixels
  smooth(); // Smooths out the drawing
  println("Available serial ports:");
  // Print all the available serial ports
  printArray(Serial.list());
  
  String portName = Serial.list()[7]; // Change this to your Arduino port
  myPort = new Serial(this, portName, 115200);
  myPort.bufferUntil('\n');          // Buffer until a newline character
  
  handleX = circleX; // Initially place handle at the center of the base
  handleY = circleY;
}

void draw() {
  background(33); // Set background to black
  fill(255); // Set text color to white
  textSize(16);
  textAlign(LEFT);
  // Display the serial data at position (10, 20)
  text("LX: " + LX + ", LY: " + LY + ", LZ: " + LZ + ", Motor L: " + motorL + ", Motor R: " + motorR, 10, 20);
  
  joystick(LX, LY, LZ); // Mid values for LX and LY
  
  tracks(motorL, motorR); // Mid-range values for motorL and motorR
}
/*
void mousePressed() {
  float d = dist(mouseX, mouseY, handleX, handleY);
  if (d < handleRadius) {
    dragging = true;
  }
}

void mouseReleased() {
  dragging = false;
}

void mouseDragged() {
  if (dragging) {
    LX = int(map(mouseX, 0,1200, 1000,2000));
    motorL = int(map(mouseX, 0,1200, 0,100));
    LY = int(map(mouseY, 0,666, 1000,2000));
  }
}*/


// Function to draw the joystick representation
void joystick(int LX, int LY, int LZ) {
  // Draw the circle at bottom left
  fill(100); // Light gray fill
  stroke(0); // Black outline
  ellipse(circleX, circleY, diameter, diameter);
  
  stroke(255); // green outline
  strokeWeight(4); // Thick line
  // Map LZ to an angle between -PI/4 to PI/4
  float rotationAngle = map(LZ, 1000, 2000, -PI/2 - PI/4, -PI/2 + PI/4);
  float startAngle = -PI/4 + rotationAngle;
  float endAngle = PI/4 + rotationAngle;
  arc(circleX, circleY, 100, 100, startAngle, endAngle); // Draw an arc from -45 degrees to 45 degrees

  // Map LX and LY to screen coordinates
  float posX = map(LX, 1000, 2000, circleX - radius, circleX + radius);
  float posY = map(LY, 1000, 2000, circleY + radius, circleY - radius);

  // Knob
  fill(255,100,20);
  stroke(133,133,133); // red outline
  strokeWeight(2); // Thick line
  ellipse(circleX, circleY, 16, 16);
  
  // Draw a line from center of the circle to the calculated position
  strokeWeight(6); // Thick line
  stroke(255,0,0); // red outline
  line(circleX, circleY, posX, posY);
  
  // Knob
  fill(255,100,20);
  strokeWeight(1); // Thick line
  ellipse(posX, posY, 20, 20);
}

void tracks(int motorL, int motorR) {
  int trackWidth = 40; // Width of each track
  int trackHeight = 100; // Height of each track
  int margin = 20; // Margin from the edges of the window

  // Coordinates for the bottom-right placement of the tracks
  int trackX1 = width - margin - trackWidth * 2 - 100; // X position for the first track
  int trackX2 = width - margin - trackWidth; // X position for the second track, with some space between
  

  // Map motor values from 1000-2000 to 0-trackHeight for the fill level
  int fillHeightL = int(map(motorL, 0, 100, 0, trackHeight));
  int fillHeightR = int(map(motorR, 0, 100, 0, trackHeight));

  // Draw the inner rectangles (filled based on motor values)
  noStroke();
  if(dir_motorL.equals("forward")) {
    fill(0,0,255);
    rect(trackX1, height - margin - fillHeightL, trackWidth, fillHeightL);
  } else {
    fill(255,0,0);
    rect(trackX1, height - margin - trackHeight, trackWidth, fillHeightL);
  }
  if(dir_motorR.equals("forward")) {
    fill(0,0,255);
    rect(trackX2, height - margin - fillHeightR, trackWidth, fillHeightR);  //////fillHeightR
  } else {
    fill(255,0,0);
    rect(trackX2, height - margin - trackHeight, trackWidth, fillHeightR);  //////fillHeightR
  }
  
  // Robi
  strokeWeight(1); // Thick line
  stroke(133,133,133); // red outline
  noFill(); // No fill for the outer rectangles
  rect(trackX1+trackWidth+10, height - margin - trackHeight+20, 80, 80);
  
  // Draw the outer rectangles (tracks)
  strokeWeight(2); // Thick line
  stroke(255,255,0); // red outline
  noFill(); // No fill for the outer rectangles
  rect(trackX1, height - margin - trackHeight, trackWidth, trackHeight);
  rect(trackX2, height - margin - trackHeight, trackWidth, trackHeight);
  
  fill(255,255,255);
  textAlign(CENTER);
  textSize(28);
  text(motorL, trackX1+trackWidth/2, height - margin - trackHeight-35);
  text(motorR, trackX2+trackWidth/2, height - margin - trackHeight-35);
  
  textSize(18);
  text(dir_motorL, trackX1+trackWidth/2, height - margin - trackHeight-10);
  text(dir_motorR, trackX2+trackWidth/2, height - margin - trackHeight-10);
}


void serialEvent(Serial myPort) {
  if(use_Serial) {
    val = myPort.readStringUntil('\n');
    // print(splitTokens(val, ": ").length);
    // println(val);
    if (val != null) {
      val = trim(val);  // Trim whitespace
      // println(val);
      
      // Parse the incoming data
      String[] data = splitTokens(val, ": "); // Split the data by tabs and colons
      if(data != null) {
        if (data.length == 15) { // Check if all elements are present
          // LX: 1500  LY: 1794  LZ: 1500  steering: ▲  motorL: 58  dir_motorL: ▲  motorR: 58  dir_motorR: ▲
          // motorL: 17  dir_motorL: forward  motorR: 17  dir_motorR: back  joystickLX: 1586  joystickLY: 1454  joystickLZ: 1692  jostickRX: 1485  jostickRY: 1509  jostickRZ: 1513  joyBtnL: 1019  joyBtnR: 1019  motorSwitch: 1  servoSwitch: 0

          LX = int(data[5].split("\t")[0]);
          LY = int(data[6].split("\t")[0]);
          LZ = int(data[7].split("\t")[0]);
          // String steering = data[7]; // Steering direction
          motorL = int(data[1].split("\t")[0]);
          dir_motorL = data[2].split("\t")[0]; // Direction for motorL
          motorR = int(data[3].split("\t")[0]);
          dir_motorR = data[4].split("\t")[0]; // Direction for motorR
    
          // Display the collected data
          print("LX: *" + LX + "* LY: *" + LY + "* LZ: *" + LZ);
          // print(", Steering: " + steering);
          print("* Motor L: *" + motorL + "*  dir_motorL *" + dir_motorL);
          println("* Motor R: *" + motorR + "*  dir_motorR *" + dir_motorR);
        }
      }
    }
  }
}

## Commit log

2024-04-10 add more CAD options
2024-04-12 Connect 5V to the the Label, Label the 7-12V to VBUS, Connect SPI GND to GNDs Add Barrel Power Label for Netclass
    [universalRobotTx.kicad_sch]
2024-04-12 Redo the routing
    [universalRobotTx.kicad_pcb]
2024-04-12 Use wide pins for RGB LED
    [universalRobotTx.kicad_pcb, universalRobotTx.kicad_sch]
2024-04-12 New footprints, edit footprints, turn stuff around
    [universalRobotTx.kicad_pcb, universalRobotTx.kicad_sch]
2024-04-12 Move design elements
    [universalRobotTx.kicad_pcb]
2024-04-12 Move one edge
    [universalRobotTx.kicad_pcb]
2024-04-12 backups kicad
2024-04-12 minor changes
    [universalRobotTx.kicad_pcb]
2024-04-12 Add gerber files
    [universalRobotTx-B_Cu.gbr, universalRobotTx-B_Mask.gbr, universalRobotTx-B_Paste.gbr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]
2024-04-12 some further minor changes
    [universalRobotTx.kicad_pcb]
2024-04-12 Some minor details added; new gerber export for production
    [universalRobotTx-B_Cu.gbr, universalRobotTx-B_Mask.gbr, universalRobotTx-B_Paste.gbr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]
2024-04-13 Add drill (.drl) files to gerber export for JLC order
    [universalRobotTx-B_Cu.gbr, universalRobotTx-B_Mask.gbr, universalRobotTx-B_Paste.gbr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]
2024-04-19 Kicad auto Backups
    [universalRobotRx.kicad_sch]
2024-04-27 Add kicad backups
2024-04-27 Buttons are now value-shifted, varia
2024-04-27 Add testing scripts for steering and processing 4 sketch for visuals
2024-04-27 Shorten PPM gap inbetween signals, somehow works
    [rx.ino, tx.ino]
2024-04-29 Add missing pde file
    [steering_visals.pde]
2024-05-06 Add play field for head movement calibration$
2024-05-06 Do not use interrupts for reading signal
2024-05-06 Attach/detach servos when needed
2024-05-07 Oopsie mororR received the same value as motorL
2024-05-08 Encode 4 switches and buttons for 1 channel
2024-05-08 Decode 4 buttons on one channel
2024-05-09 Finalize motor controls for driving
2024-05-09 Disable steering switch
2024-05-09 Fine tune smoothing head servos
2024-05-20 Match servo value to physical servo arm
2025-09-30 Add foam insert drawing
2025-09-30 update kicad files
2025-10-01 Debug prints for trim pots
2025-10-01 Bugfixes for iBUS signal generation
    [tx.ino]
